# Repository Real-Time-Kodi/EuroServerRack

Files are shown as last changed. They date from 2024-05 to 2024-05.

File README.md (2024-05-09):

# EuroServerRack

This is a project based on KronBjorn's [6 Inch Rack](https://github.com/KronBjorn/SixInchRack).  
It takes their design and removes the handles, and scales it to 128mm wide to fit in a eurorack.
The standard 1u was changed to be 5mm to match up with the eurorack standard's HP rack units. Ears and screwholes were scaled to use m3 for just about everything and cheaply available #6x1/2" screws(3mm x 10mm) for assembly.
It is inteded that you use a flexATX power supply and poke female 4 pin molex out of the back of each enclosure. In the future there will be an option for using barrel connectors added to all of the customizers.

For pictures have a look here:
 - [Printables Collection](https://www.printables.com/@Beefdip_176978/collections/1432728)
 - [Power Supply Control Module](https://www.printables.com/model/871111-atx-power-supply-control-module-for-eurorack)
 - [FlexATX Mounting Plate](https://www.printables.com/model/871077-flex-atx-power-supply-eurorack-mount)

The project is a scaled down version of the familiar 19" rack standard, with the following size:
 - 1U(HP) is 5mm
 - The front plate is 128.5mm wide
 - The mounting holes are 122.5 mm center-to-center
 - The inside distance between the two vertical profiles is 110 mm
 - The ears protrude 9.25mm
 - The screw holes are sized for M3 cap screws

## I want to print a mount for a specific component
You can get info and STLs for specific components here:
 - [Printables Collection](https://www.printables.com/@Beefdip_176978/collections/1432728)]
 - [3u Eurorack Enclosure](https://www.printables.com/model/871019-3u-eurorack)
 - [Jetson Nano Chassis](https://www.printables.com/model/871200-eurorack-chassis-for-jetson-nano)
 - [Raspberry Pi B Chassis](https://www.printables.com/model/871206-eurorack-chassis-for-raspberry-pi-b)(and le potato)
 - [Power Supply Control Module](https://www.printables.com/model/871111-atx-power-supply-control-module-for-eurorack)
 - [FlexATX Mounting Plate](https://www.printables.com/model/871077-flex-atx-power-supply-eurorack-mount)
 - [Passthrough Chassis](https://www.printables.com/model/871212-eurorack-passthrough-plate)
 - [Hotswap Bay](https://www.printables.com/model/871097-eurorack-hotswap-bay)
 - [Fan Mounts and Ductwork](https://www.printables.com/model/871048-eurorack-fan-and-ductwork)

## I want to make a new cabinet for my favourite module
Start by inspecting this file for inspiration _RackCabinets/RaspberryPi34ModelB/usb_front.scad_, and take a look at the how to section below.

1. Create a new file that includes _sixinch_library.scad_
2. Customize all the parts needed for your cabinet
3. Create a new folder with you project, and anything else needed like print descriptions
4. If you like, create a Printables build with pictures and your stl, and add a link in this file

## Quick How To
A cabinet consist of five parts:
- Front plate
- Back plate
- Cabinet
- Lid
- Handles

In a new file, include _sixinch_library.scad_. For each of the parts, there is module in the library where you can specify the most commonly used features like round and square holes, and pegs for supporting PCB's etc.  
The deafult modules obviously does not support everything you need, but should give you a good start for further customization. Feel free to add functionality to the library.

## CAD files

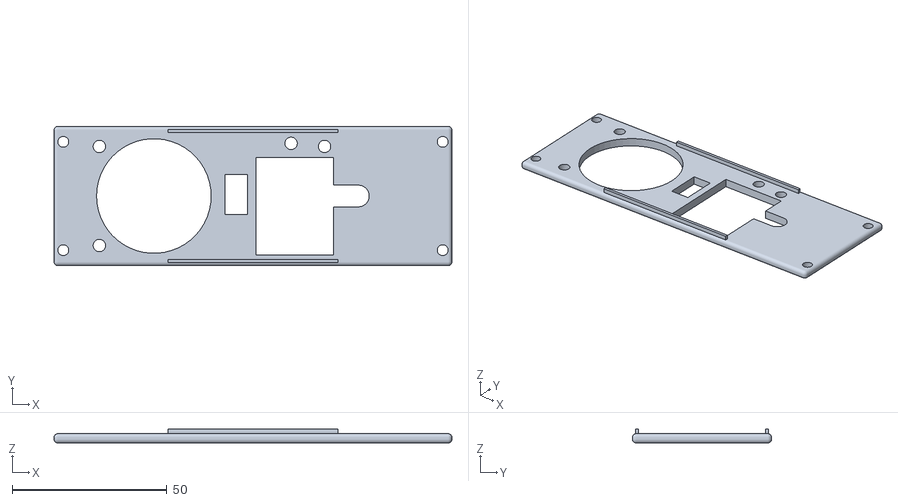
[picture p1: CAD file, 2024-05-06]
RackCabinets/FlexATX/flexatx.stl
128.5 x 45.0 x 4.50

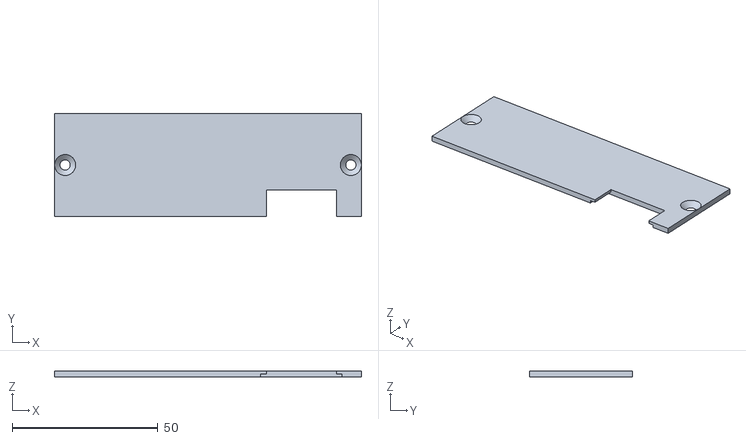
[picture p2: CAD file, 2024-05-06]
RackCabinets/JetsonNano/jetson_back.stl
105.3 x 35.3 x 2.00

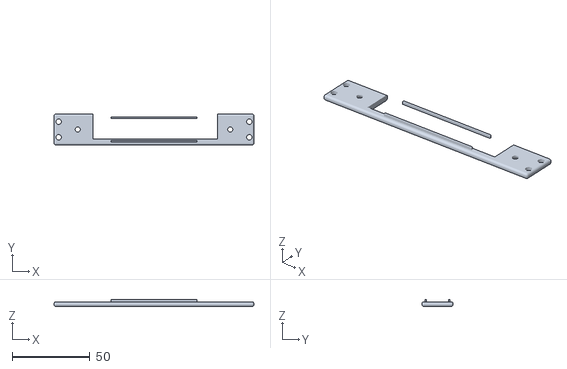
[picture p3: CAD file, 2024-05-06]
RackCabinets/Passthrough/passthrough_frontplate.stl
128.5 x 20.0 x 4.50

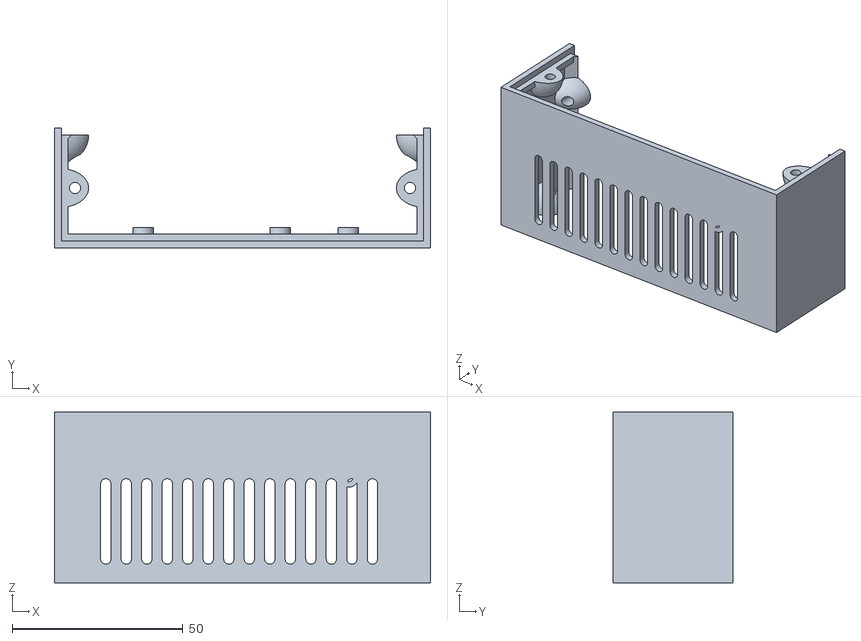
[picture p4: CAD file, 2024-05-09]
RackCabinets/PDU/PDU_Chassis.stl
110.0 x 35.0 x 50.0

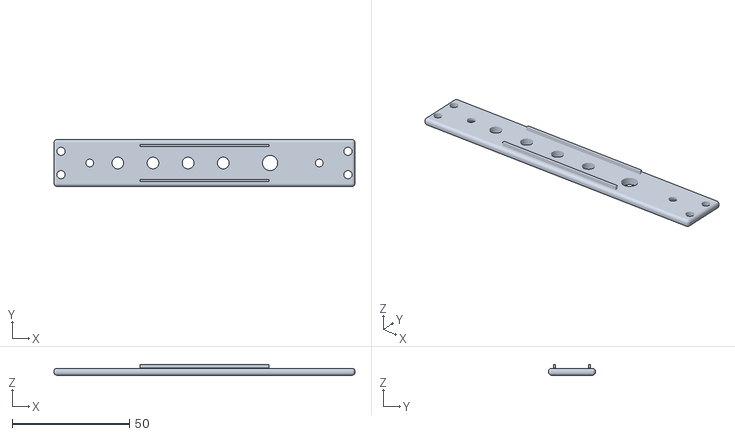
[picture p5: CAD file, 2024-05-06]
RackCabinets/PSU Control/psu_front.stl
128.5 x 20.0 x 4.50

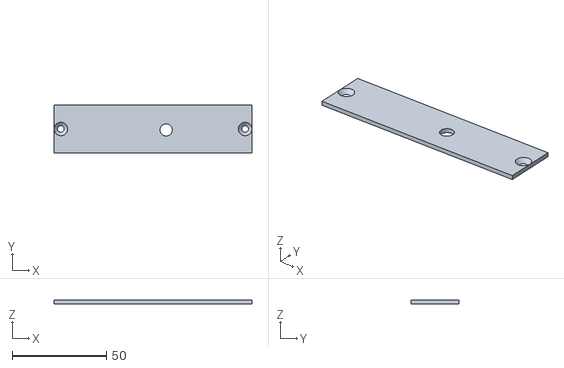
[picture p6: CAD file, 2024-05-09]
RackCabinets/RaspberryPi34ModelB/pi_backplate_barrel.stl
105.3 x 25.3 x 2.00

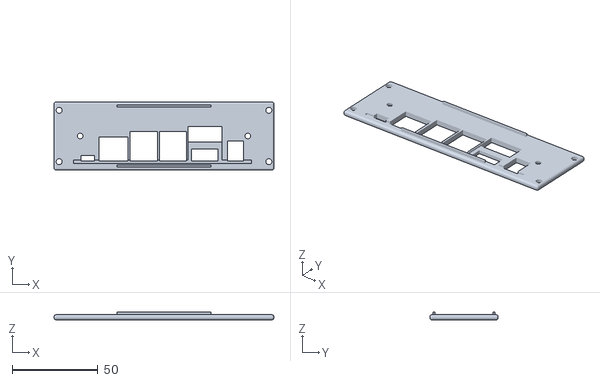
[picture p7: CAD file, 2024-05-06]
RackCabinets/JetsonNano/jetson_front.stl
128.5 x 40.0 x 4.50

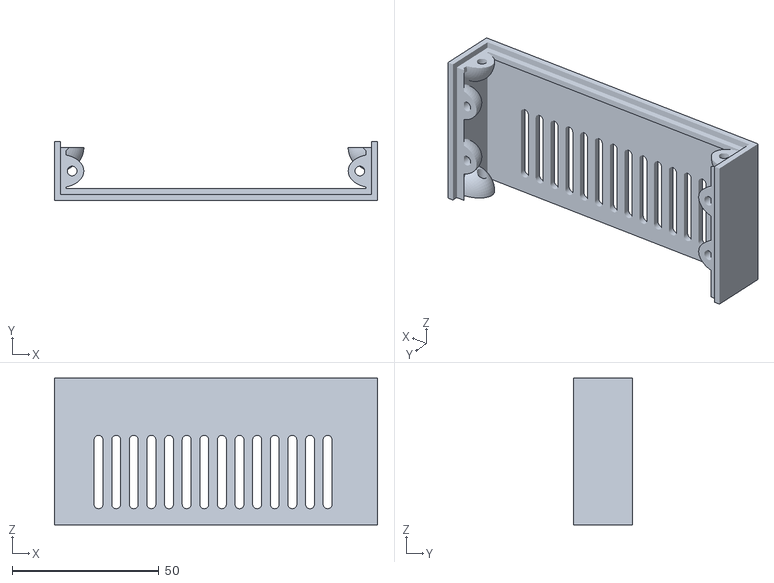
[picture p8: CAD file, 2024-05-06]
RackCabinets/Passthrough/passthrough_cabinet.stl
110.0 x 20.0 x 50.0

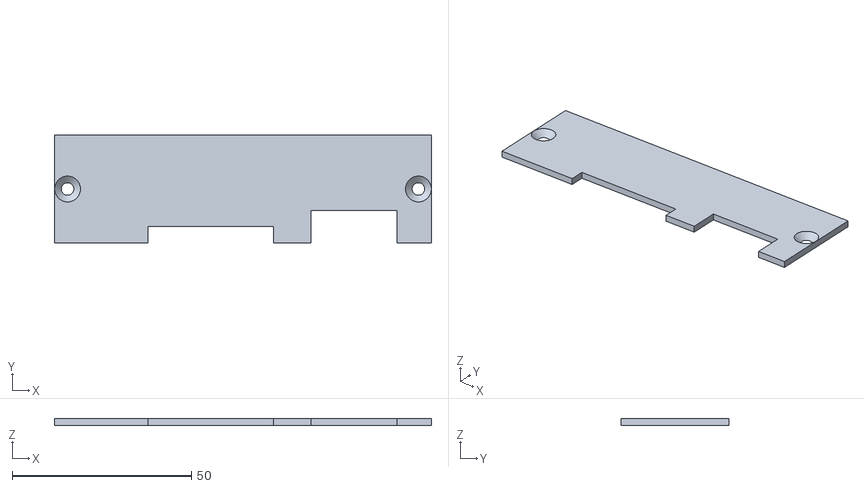
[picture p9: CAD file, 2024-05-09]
RackCabinets/PDU/PDU_Back.stl
105.3 x 30.3 x 2.00

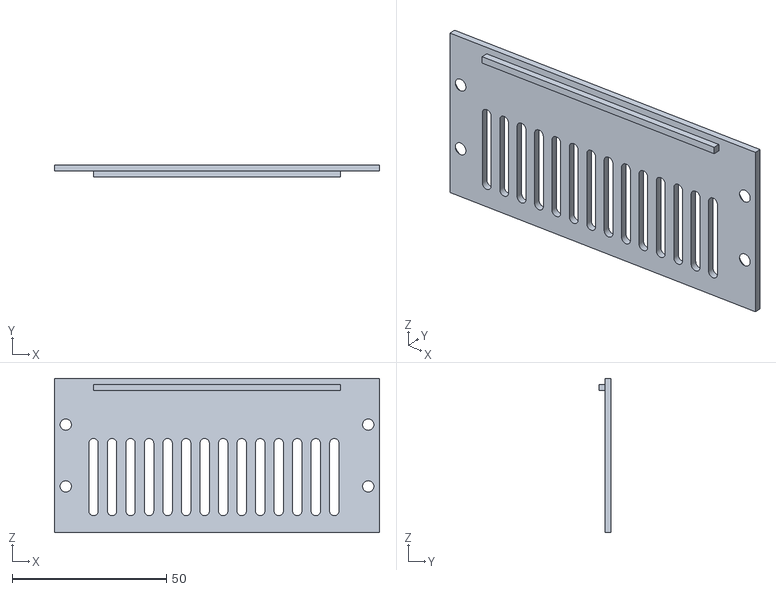
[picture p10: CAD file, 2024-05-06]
RackCabinets/PSU Control/psu_lid.stl
105.3 x 4.00 x 50.0

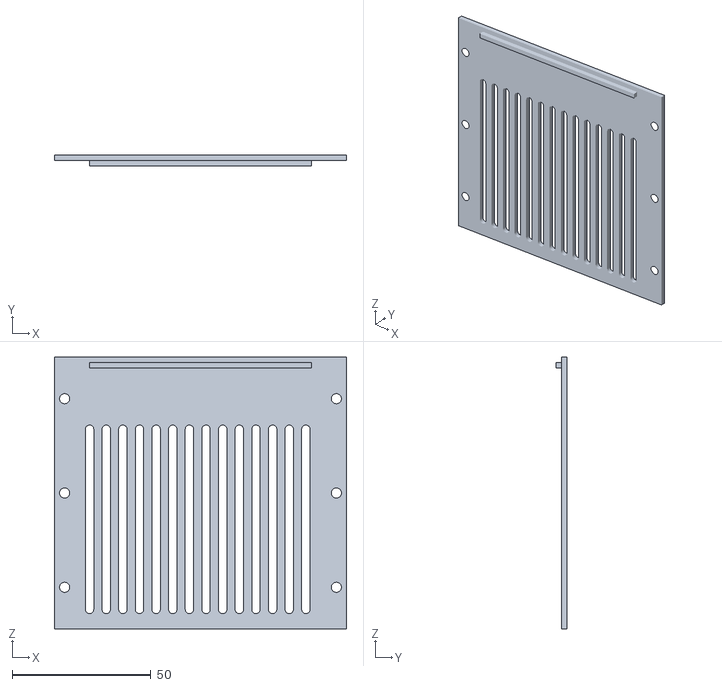
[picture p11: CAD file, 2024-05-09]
RackCabinets/RaspberryPi34ModelB/pi_lid.stl
105.3 x 4.00 x 98.0

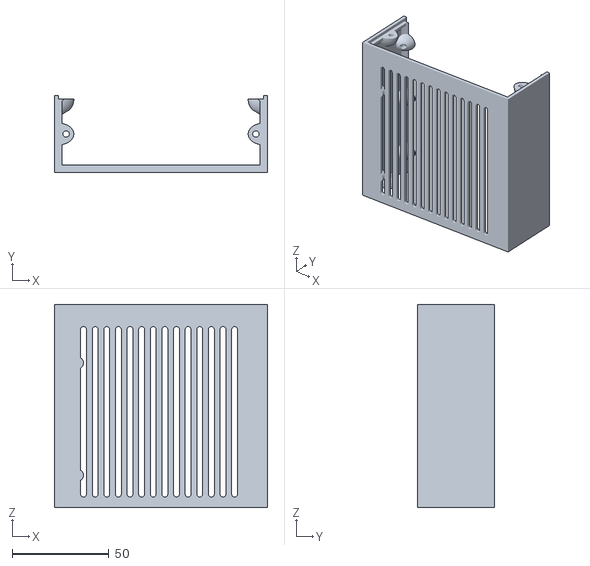
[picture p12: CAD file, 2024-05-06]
RackCabinets/JetsonNano/jetson_chassis.stl
110.0 x 40.0 x 105.0

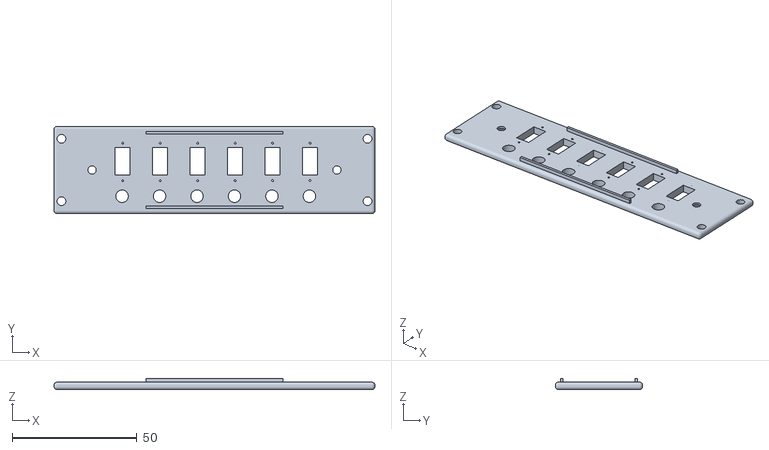
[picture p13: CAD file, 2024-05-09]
RackCabinets/PDU/PDU_Front.stl
128.5 x 35.0 x 4.50

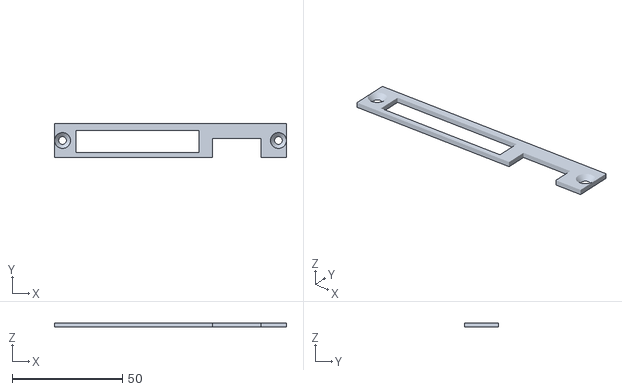
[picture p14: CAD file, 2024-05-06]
RackCabinets/PSU Control/psu_back.stl
105.3 x 15.3 x 2.00

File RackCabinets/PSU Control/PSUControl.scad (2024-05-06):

/* Power Supply Control Eurorack Enclosure Generator 
 * Modified for purpose by @realtimekodi
 * https://github.com/Real-Time-Kodi/EuroServerRack/
 * Initially designed by KronBjorn
 * https://github.com/KronBjorn/SixInchRack
 * 
 * Creative Commons 4.0 Share Alike With Attribution -- Non-Comercial
 * http://creativecommons.org/licenses/by-nc-sa/4.0/
*/
include<../sixinch_library.scad>

print_frontplate_sml = false;
print_cabinet_sml    = false;
print_lid            = false;
print_rear           = true;


Vent_Length          = 22;
Vent_Frequency       = 6;
Vent_Thickness       = 3;
standoff_hole_size   = 2.3;//2.3 for m2.5, 2.8 for m3
Depth                = 50; //Depth of the case min is somewhere around 98
hp                   = 4; //How many hp units you want this to be min is prob 5

if(print_frontplate_sml){ // Frontplate //
    w=boffset-gauge_box;
    square_hole        = [];
    round_hole         = [[w+20,hp*2.5,5],[w+35,hp*2.5,5],[w+50,hp*2.5,5],[w+65,hp*2.5,5],
        [w+85,hp*2.5,6.5]];
    round_peg          = [];   
    screw_side_front   = [hp/2];
    screw_top          = [];
    screw_bottom_front = [];
    
    frontplate(hp,square_hole,round_hole,round_peg,screw_side_front,screw_top,screw_bottom_front);
}

if(print_cabinet_sml){ // Cabinet //  
    w=pi_offset_x;
    h=pi_offset_y;
    screw_bottom_front = [];
    screw_side_front   = [hp/2];
    round_peg          = [[84,Depth-19,6,standoff_hole_size,6]];
    cabinet(Depth,hp,screw_bottom_front,round_peg,screw_side_front);
}

if(print_lid){ // Lid // 
    screw_front = [];//mm
    screw_back  = [];//mm
    lid(Depth,hp,screw_front,screw_back);        
}

if(print_rear){  // Back plate //    
    square_hole  = [
        [10,2.5,56,10],//24
        [72,0,22,9],//molex
    ];
    round_hole   = [];
    screw_top    = [];//mm
    screw_bottom = [];//mm
    screw_side   = [hp/2];
    back_plate(hp,Depth,screw_top,screw_bottom,screw_side,square_hole,round_hole);
}  

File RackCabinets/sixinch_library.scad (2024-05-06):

/* Eurorack Enclosure Generator 
 * Modified for purpose by @realtimekodi
 * https://github.com/Real-Time-Kodi/EuroServerRack/
 * Initially designed by KronBjorn
 * https://github.com/KronBjorn/SixInchRack
 * 
 * Creative Commons 4.0 Share Alike With Attribution -- Non-Comercial
 * http://creativecommons.org/licenses/by-nc-sa/4.0/
*/


$fn = 50*1;



//Constants, do not change !
sixinch     = 128.5*1;       //Total width of cover plate
rackhole    = 122.5*1;  //sixinch-6; //Distance between rack holes
width       = 110;   // size of box behind the cover plate
unit        = 5; // HP unit height(5.08 but we want wiggle room)
gauge       = 3*1;
gauge_box   = 2*1;
boffset     = (sixinch-width)/2;//used for setting the center

// Default Vent Params
Vent_Length    = 30;
Vent_Thickness = 2;
Vent_Frequency = 8;

//Cabinet screws in mm. They can be changed a little
screw_head        = 7.4; 
screw_head_height = 2.2;  
screw_dia         = 3.3;   
screw_hole        = 2.99; 
screw_length      = 18;
nut_4mm           = 8.1; 
slip              = 0.35;
rack_screwhole    = 3.5;//Usually m3 + 0.5 for space


module chimney() {    
for(i=[0:Vent_Frequency:80]){
    echo(i);
    translate([boffset + (width-80)/2  +i,-1,10]){
        minkowski(){
            cube([0.01,200,Vent_Length]);    
            sphere(d=Vent_Thickness,h=1);        
        }
    }
}
}



 
     
 module back_plate(u,dp,screw_top,screw_bottom,screw_side,square_hole,round_hole){
    
     difference(){
        union(){
            translate([boffset+gauge_box+slip,gauge_box+slip,gauge+dp-gauge_box]){
                cube([width-2*gauge_box-2*slip, u*unit-2*gauge_box-2*slip, gauge_box]);
            }
        }
     
     //Square holes
        for(i=[0:len(square_hole)-1]){
            x = square_hole[i][0];
            y = square_hole[i][1];
            w = square_hole[i][2];
            h = square_hole[i][3];            
            translate([x+boffset+gauge_box,y+gauge_box,dp-1]){cube([w,h,gauge+2]);}        
        } 
    
    //Round holes
    if(len(round_hole)>0){
        for(i=[0:len(round_hole)-1]){
            x = round_hole[i][0];
            y = round_hole[i][1];
            dia = round_hole[i][2];
            translate([boffset+gauge_box+x,gauge_box+y,dp-4]){  cylinder(d=dia,h=10); }
        }
    }
        
    
    //Screw holes
    if(len(screw_top)>0){
        for(i=[0:len(screw_top)-1]){
            p = screw_top[i];
            translate([p,unit*u-gauge_box-4,gauge+dp+0.1]){rotate([0,180,0]){screw();}}
            translate([sixinch-p,unit*u-gauge_box-4,gauge+dp+0.1]){rotate([0,180,0]){screw();}} 
        }
    }
    if(len(screw_bottom)>0){
        for(i=[0:len(screw_bottom)-1]){
            p = screw_bottom[i]; 
            translate([p,gauge_box+4     ,gauge+dp+0.1]){rotate([0,180,0]){screw();}}
            translate([sixinch-p,    gauge_box+4    ,gauge+dp+0.1]){rotate([0,180,0]){screw();}} 
        }
    }
    
    if(len(screw_side)>0){
        for(i=[0:len(screw_side)-1]){
            p = screw_side[i];  
            translate([sixinch-boffset-6,    unit*p    ,gauge+dp+0.1]){rotate([0,180,0]){screw();}} 
            translate([boffset+6,    unit*p    ,gauge+dp+0.1]){rotate([0,180,0]){screw();}}   
        }
    }
}
}

 
 


module peg(x,y,od,id,he){
    translate([x,y,0]){
        rotate([-90,0,0]){
            difference(){
                cylinder(r=od/2,h=he);
                translate([0,0,-0.5]){cylinder(r=id/2,h=he+1);}
            }        
        }
    }
}



module screwtrap(){  
    difference(){
        translate([0,0,5]){
            intersection(){
                scale([1,1,0.7]){
                    sphere(r=8);     
                }   
                translate([0,-0.001,-10]){  cube([20,20,20]);}
            }
        }  
        translate([2,4,5]){
            rotate([90,90,90]){
               translate([0,0,-10]){ cylinder(r=screw_dia/2,h=20,$fn=100);}
            }
        }    
    }
}





module nuttrap(){
    difference(){
        linear_extrude(10){
            polygon(points=[[0,0],[8,0],[2,8],[0,8]]);
        }
        translate([2,4,5]){
            rotate([90,90,90]){
                cylinder(r=nut_4mm/2,h=20,$fn=6);
            }
        }
        translate([2,4,5]){
            rotate([90,90,90]){
               translate([0,0,-10]){ cylinder(r=screw_dia/2,h=20,$fn=100);}
            }
        }
    }
}








module cabinet (dp,u,screw_bottom_front,round_peg,screw_side_front){
    difference(){
        box(dp,u,screw_bottom_front,round_peg,screw_side_front);
               

              
        }
       
    }





module box(dp,u,screw_bottom_front,round_peg,screw_side_front){
    difference(){
        translate([boffset,0,gauge]){
            difference(){
                cube([width,u*unit,dp]);
                translate([gauge_box,gauge_box,-1]){ cube([width-gauge_box*2,u*unit,dp+2]);}                        
            }            
        }
        //CHIMNEY(Air Slots)
        chimney(); 
    }
    
    //Screw mounts on the bottom plate
    if(len(screw_bottom_front)>0){
        for(i=[0:len(screw_bottom_front)-1]){
            p = screw_bottom_front[i];
            translate([p+5,gauge_box,gauge]){rotate([0,-90,0]){screwtrap();}}
            translate([sixinch-p+5,gauge_box,gauge]){rotate([0,-90,0]){screwtrap();}}        
            translate([p-5,gauge_box,gauge+dp-gauge_box]){rotate([0,90,0]){screwtrap();}}
            translate([sixinch-p-5,gauge_box,gauge+dp-gauge_box]){rotate([0,90,0]){screwtrap();}}
       }
   }
    
   //Screw mounts on the side of cabinet
   if(len(screw_side_front)>0){
        for(i=[0:len(screw_side_front)-1]){
            p = screw_side_front[i]*unit;
                translate([boffset+gauge_box,p-5,gauge]){rotate([0,-90,-90]){screwtrap();}}
                translate([sixinch-boffset-gauge_box,p+5,gauge]){rotate([0,-90,90]){screwtrap();}}    
                translate([boffset+gauge_box,p+5,gauge+dp-gauge_box]){rotate([0,90,-90]){screwtrap();}}
                translate([sixinch-boffset-gauge_box,p-5,gauge+dp-gauge_box]){rotate([0,90,90]){screwtrap();}}    
        }
    }
    
    //Screw mounts for lid. Two on each side, three if dp>90
    translate([boffset+gauge_box,unit*u-gauge_box,gauge+10]){rotate([0,0,-90]){screwtrap();}}
    translate([boffset+gauge_box,unit*u-gauge_box,gauge+dp-10-10]){rotate([0,0,-90]){screwtrap();}}            
    translate([sixinch-boffset-gauge_box,unit*u-gauge_box,gauge+10+10]){rotate([180,0,-90]){screwtrap();}}
    translate([sixinch-boffset-gauge_box,unit*u-gauge_box,gauge+dp-10-10+10]){rotate([180,0,-90]){screwtrap();}}
    if(dp>90){
        translate([sixinch-boffset-gauge_box,unit*u-gauge_box,gauge+dp/2-5+10]){rotate([180,0,-90]){screwtrap();}}
        translate([boffset+gauge_box,unit*u-gauge_box,gauge+dp/2-5]){rotate([0,0,-90]){screwtrap();}}
    }
        
    //Lid rest bar 
    translate([boffset+gauge_box,unit*u-3-gauge_box,gauge]){
        linear_extrude(dp-gauge_box){polygon (points=[[0,0],[3,3],[0,3]]);}
    }
    translate([sixinch-boffset-gauge_box,unit*u-3-gauge_box,gauge]){
        linear_extrude(dp-gauge_box){polygon (points=[[0,0],[-3,3],[0,3]]);}
    }
        
    // Back/front rest bar
    translate([0,0,dp+gauge-2-gauge_box]){
        difference(){
            translate([boffset,0,0]){  cube([width,unit*u-gauge_box,2]);  }
            translate([boffset+gauge_box+2,gauge_box+2,-1]){  cube([width-2*gauge_box-4,unit*u,4]);  }        
        }
    }
              
    //PEGS Relative to inside corner
    translate([boffset+gauge_box,0,gauge]){ 
        if(len(round_peg)>0){
            for(i=[0:len(round_peg)-1]){
                x = round_peg[i][0];
                y = round_peg[i][1];
                od = round_peg[i][2];
                id = round_peg[i][3];  
                he = round_peg[i][4];      
                translate([x,0,y]){peg(0,0,od,id,he); }
             }        
        }
    }    
}


module lid(dp,u,screw_front,screw_back){    

    difference(){
    union(){ 
        if(len(screw_front)>0){
            for(i=[0:len(screw_front)-1]){                                
                p = screw_front[i];                
                translate([p-5,unit*u-gauge_box,gauge]){rotate([0,-90,180]){screwtrap();}}
                translate([sixinch-p-5,unit*u-gauge_box,gauge]){rotate([0,-90,180]){screwtrap();}}
            }
        }        
        if(len(screw_back)>0){
            for(i=[0:len(screw_back)-1]){                                
                p = screw_back[i];                                
                translate([p+5,unit*u-gauge_box,gauge+dp-gauge_box]){rotate([0,90,180]){screwtrap();}}
                translate([sixinch-p+5,unit*u-gauge_box,gauge+dp-gauge_box]){rotate([0,90,180]){screwtrap();}} 
            }
        }
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

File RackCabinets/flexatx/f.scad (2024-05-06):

include<../sixinch_library.scad>

print_frontplate_sml = true;

Depth                = 98; //Depth of the case min is somewhere around 98
standoff_hole_size   = 2.3;//2.3 for m2.5, 2.8 for m3
hp                   = 9; //Might get away with 8
offset_y             =2.5;
gauge_box=1;

if(print_frontplate_sml){ // Frontplate //
    w=boffset+2-1;//the 2 is a magic number, sorry
    square_hole        = [
        [w+55,offset_y+1,25,31.5],//IEC
        [w+45,offset_y+14,7.3,13],//Voltage switch
        [w+79,offset_y+16.5,9,7]];//IEC Hole
    round_hole         = [
        [w+4.4,offset_y+4,4],//mount
        [w+4.4,offset_y+36,4],//mount
        [w+66.3,offset_y+37,4],//mount
        [w+77.1,offset_y+36,4],//mount
        [w+22,offset_y+20,37],//fan
        [w+88,offset_y+20,7]];//iec
    round_peg          = [];   
    screw_side_front   = [];
    screw_top          = [];
    screw_bottom_front = [];
    
    frontplate(hp,square_hole,round_hole,round_peg,screw_side_front,screw_top,screw_bottom_front);
}

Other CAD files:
RackCabinets/RaspberryPi34ModelB/pi4_front.stl
RackCabinets/JetsonNano/jetson_lid.stl
RackCabinets/PDU/PDU_Top.stl
RackCabinets/PSU Control/psu_cabinet.stl
RackCabinets/PSU Control/thingiverse_customizer.scad
RackCabinets/FlexATX/flexatx.scad
RackCabinets/JetsonNano/jetson.scad
RackCabinets/PDU/Holddown.FCStd
RackCabinets/PDU/Holddown.stl
RackCabinets/PDU/PDU.scad
RackCabinets/Passthrough/Passthrough.scad
RackCabinets/Passthrough/thingiverse_customizer.scad
RackCabinets/RaspberryPi34ModelB/pi3_front.stl
RackCabinets/RaspberryPi34ModelB/pi_backplate_molex.stl
RackCabinets/RaspberryPi34ModelB/pi_chassis.stl
RackCabinets/RaspberryPi34ModelB/usb_back.scad
RackCabinets/RaspberryPi34ModelB/usb_front.scad
RackCabinets/ThingiverseCustomizer/thingiverse_customizer.scad

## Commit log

2024-05-06 Initial commit for Eurorack Mods
    [back.stl, cabinet.stl, enclosure.scad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]
2024-05-06 Added headers
    [PSUControl.scad, Passthrough.scad, back.stl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]
2024-05-09 Added Rack PDU models
    [PDU.scad, usb_front.scad]
2024-05-09 added holddown
    [Holddown.FCStd]
2024-05-09 Added built STLs
    [Holddown.stl, PDU_Back.stl, PDU_Chassis.stl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]
